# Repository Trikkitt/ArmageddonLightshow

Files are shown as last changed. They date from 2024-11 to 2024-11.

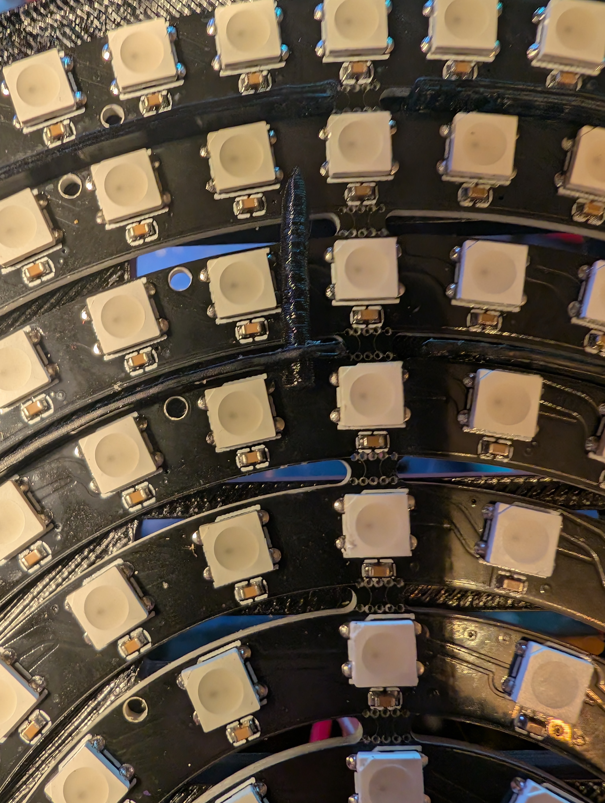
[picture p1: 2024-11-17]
Electronics/PXL_20241116_232850254.jpg

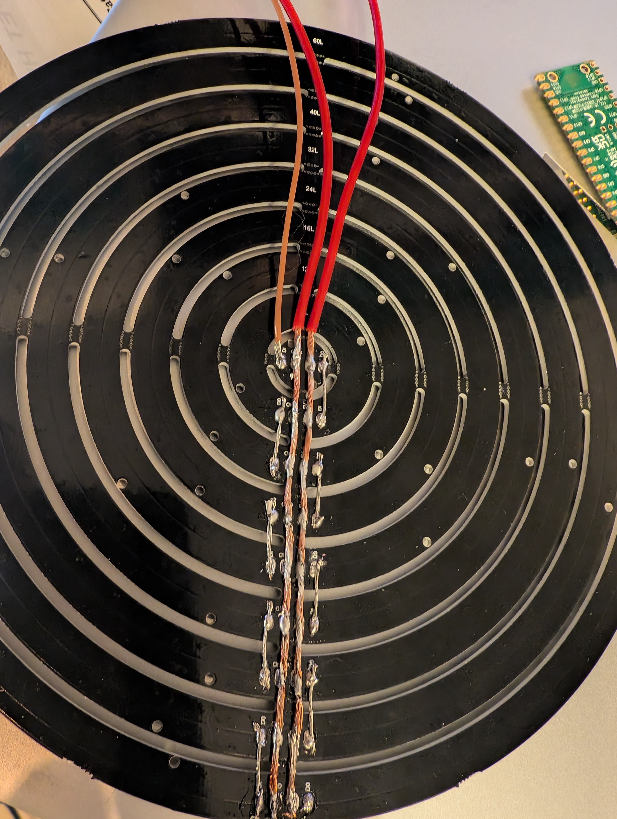
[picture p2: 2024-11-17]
Electronics/PXL_20241116_205644635.jpg

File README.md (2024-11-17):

Armageddon LaerTag Tournament.

This page will continue to be updated as the software and design is updated.  So please check back.

You can reach me via the website https://trikkitt.com or via Mastodon trikkitt@mastodon.social

Please see the readme files in each folder to explain how this all fits together.

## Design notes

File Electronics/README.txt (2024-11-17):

You will need the following:

RaspberryPi Pico or Pico W.
USB C Port - https://amzn.eu/d/fpsSOgz image is included in this folder.
Toggle Switch - Only if you want to manual power switch or a power switch to isolate the Pico from the LEDs if you're wanting to play around with the Pico software.
LED Rings - These are 241 LEDs in total over 9 rings, the smallest having 1 LED the largest having 60.  You will need to manually resolder all the connections because they're just too big and bulky - although you could expand the CPU Holder part to accommodate them it would make the back fairly chunky.
USB C 5volt 5amp Power Supply - These are readily available as power supplies for RaspberryPi 5 computers.  
Wires - Keep in mind they could be carrying up to 5amps, so make sure they're suitably specified for the task.

At maximum brightness these LEDs could be pulling up to 9amps.  For this reason the software defaults to limiting the brightness and will typically keeps its power use under 3amps using the default settings.  You can dial up the brightness, but be aware that you may find the higher power demand causes the power supply to cut out or the Pico to crash or reboot due to unstable power.  Some effects are significantly more power hungry than others so the reboots might only happen when certain effects run.  You can optionally ignore the USB C port and install something else to supply power at significantly more amps.  During tests turning all LEDs up to a value of 150 out of 255 caused power consumption to hit 5amps, while 100 out of 255 saw around 3.5amps.  The maxbrightness value in the script defaults to 0.5 which is about 128, pulling a max of about 3amps.

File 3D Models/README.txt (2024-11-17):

All models can be printed without supports except for the "CPU Mounting" model, which requires supports.  The "Pin" model should be printed with a decent brim.

For the best finish I've printed mine onto a textured bed.  The top and bottom layers of the front are printed with a Hilbert curve to avoid the appearance of long lines that can be fairly visible in some prints with monotonic top and bottom layers.  I also printed the bottom layer with one wall only to get the most detail from the phasers.  Infill is Gyroid to give the edge a nice look when illuminated.  You may want to play around with the alignment of the phasers when setting up the print.  You may wish to rotate the phasers to a position that you favour, be aware that the design makes the hanging point be exactly midway between two the retaining legs of the front.

Everything is printed in black except for the front which is printed in transparent filament along with black (or your colour of choice) for the phasers and Armageddon logo.

You need one of each item except for the clips, of which you will need 6, although I recommend printing a few spares, and the pins of which you will need 3 but you may well want to print a few spares.

I do not recommend using PLA for this, the LEDs can get quite warm.  So probably aim for a higher temperature filament.  I've used PETG just fine, which also gives everything a little flexibility.

This was created in TinkerCad and you can access the design there in https://www.tinkercad.com/things/3HTQpiZR87c-armageddon-disc-final

Assembly steps are as follows:
1 - Get your parts 3D printed and get your electronics prepared as per the electronics instructions and photos - except do not solder the LED rings to the main electronics as they must pass through a hole in one of the plastic parts.
2 - Place the LED rings onto the back plate, the raised ridges of the back plate should pop through the gaps between the rings.  Ensure the wires go through the large long opening at the back.
3 - Fully assemble the CPU holder part electronics, including attaching the LED rings wires onto the electronics in the CPU holder.
4 - Ensure the wires are as neatly retained as possible to avoid snagging.  
5 - Place the CPU retainer over the USB C port so that it holds the RaspberryPi Pico in place
6 - Place the CPU holder against the back plate so that the raised parts fit inside the grooves, then slide slowly up making sure no wires are snagged.  You will know when it has fully reached its end position as the bottom two round holes in the black plate will match up with two round holes of the CPU holder.
7 - Place the back plate onto the clear front so that the legs pop through.  Be sure to orientate the front so that your desired phaser as at the centre top.
8 - Place the clips around each clear leg to hold the front onto the back plate.

Extra things: I recommend making sure all the plastics fit together before you put the electronics into it.  This just ensures your prints are good.  The same applies to the electronics, make sure you've tested it before you fully assemble.

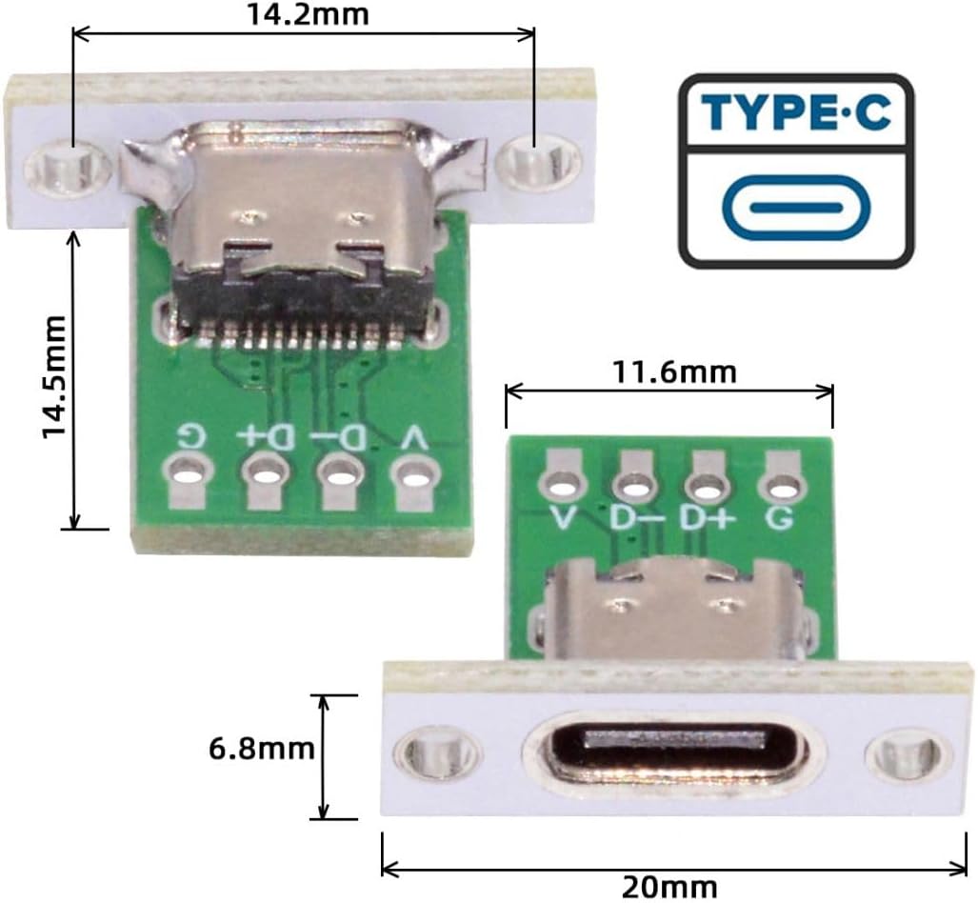
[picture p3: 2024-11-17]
Electronics/USB-C Port.jpg

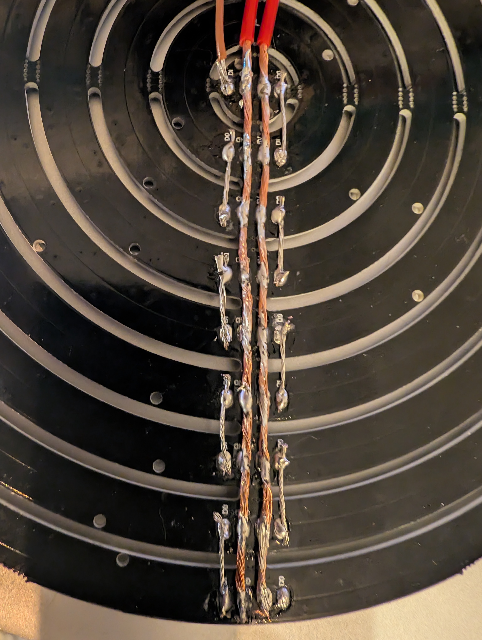
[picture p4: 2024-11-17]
Electronics/PXL_20241116_205639761.MP.jpg

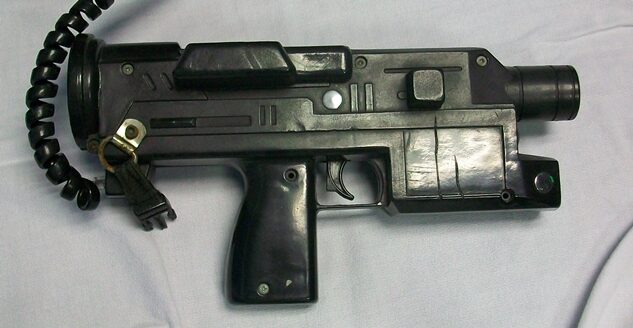
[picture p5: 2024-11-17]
SourceMedia/ActualReality Phaser.jpg

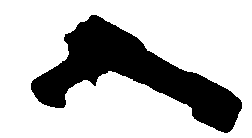
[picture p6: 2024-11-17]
SourceMedia/PhotonPhaser1.bmp

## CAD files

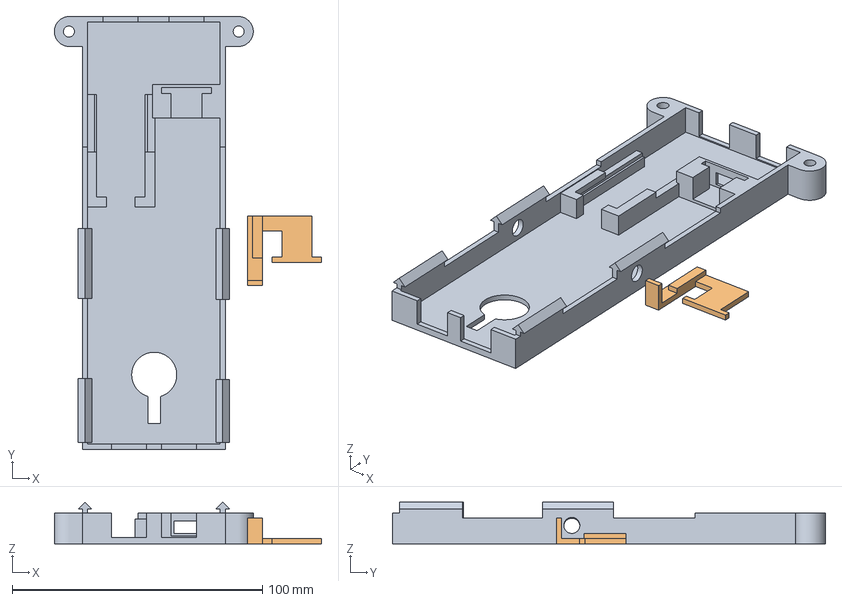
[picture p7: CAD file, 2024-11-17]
Bambu Projects/Armageddon Main CPU Holder.3mf
106.8 x 173.0 x 16.7 mm
Armageddon Disc CPU Mounting.stl
Armageddon Disc CPU Mounting Retainer.stl

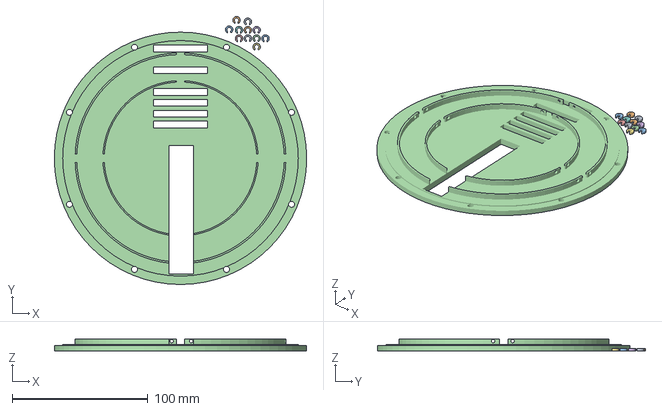
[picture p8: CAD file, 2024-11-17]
Bambu Projects/Armageddon Main Back Full.3mf
186.0 x 197.5 x 9.00 mm
Armageddon Disc Clip.stl x 11
Armageddon Disc Back.stl

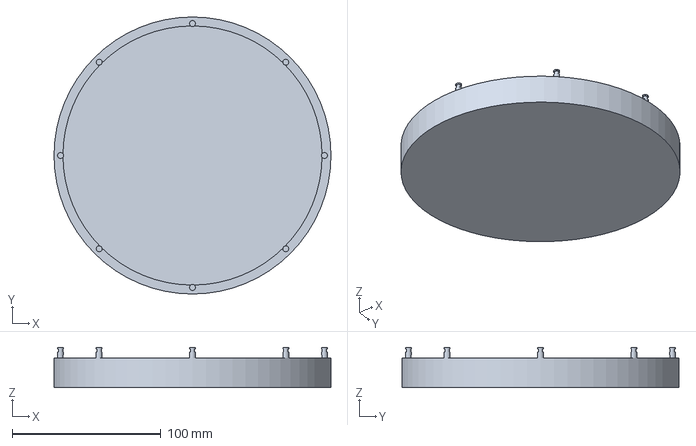
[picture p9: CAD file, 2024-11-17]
Bambu Projects/Armageddon Main Front Full.3mf
186.0 x 186.0 x 27.0 mm

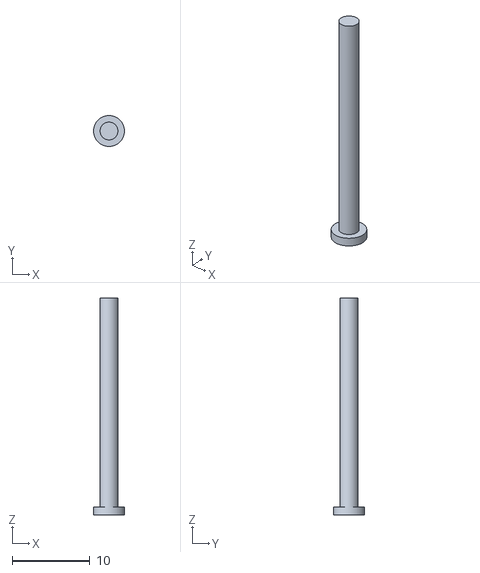
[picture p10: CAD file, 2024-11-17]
3D Models/Armageddon Disc Pin.stl
4.00 x 4.00 x 28.0

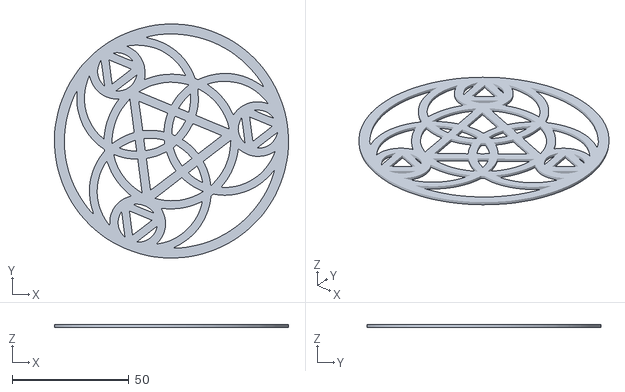
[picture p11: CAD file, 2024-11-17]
3D Models/Armageddon Disc Logo.stl
100.0 x 100.1 x 1.20

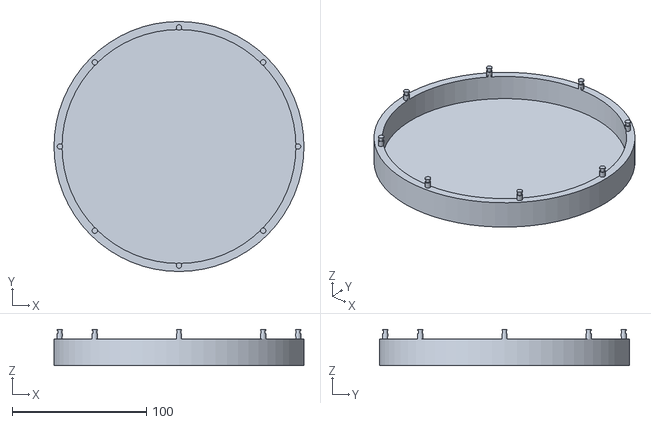
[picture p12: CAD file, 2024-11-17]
3D Models/Armageddon Disc Front.stl
186.0 x 186.0 x 27.0

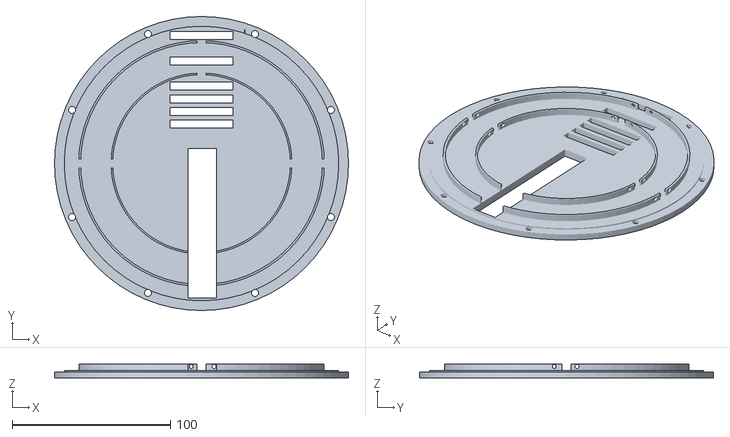
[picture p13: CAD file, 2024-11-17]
3D Models/Armageddon Disc Back.stl
186.0 x 186.0 x 9.00

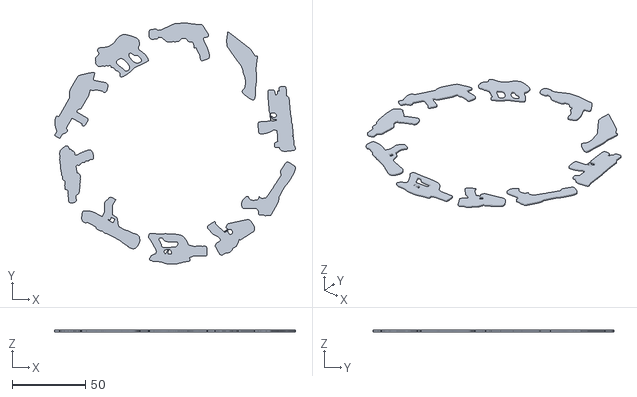
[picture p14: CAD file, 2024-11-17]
3D Models/Armageddon Disc Phasers.stl
165.0 x 165.0 x 1.20

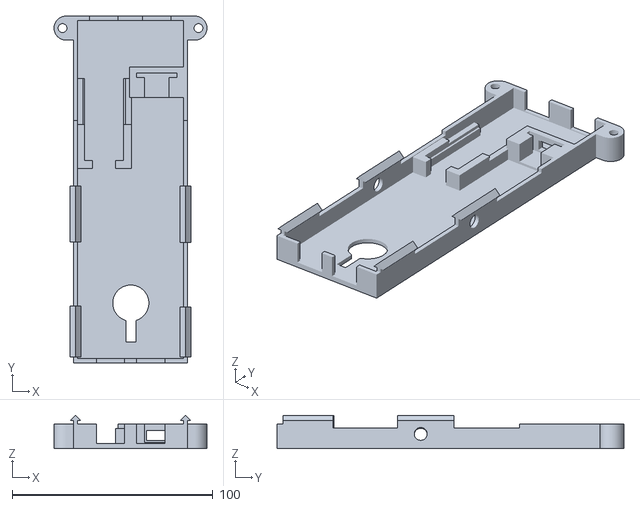
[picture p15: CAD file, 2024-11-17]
3D Models/Armageddon Disc CPU Mounting.stl
76.3 x 173.0 x 16.7

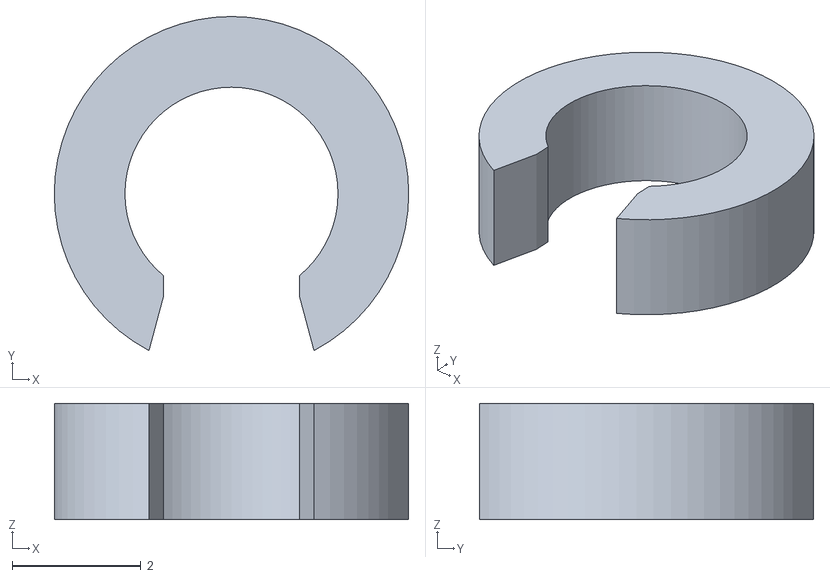
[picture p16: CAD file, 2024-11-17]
3D Models/Armageddon Disc Clip.stl
5.50 x 5.18 x 1.80

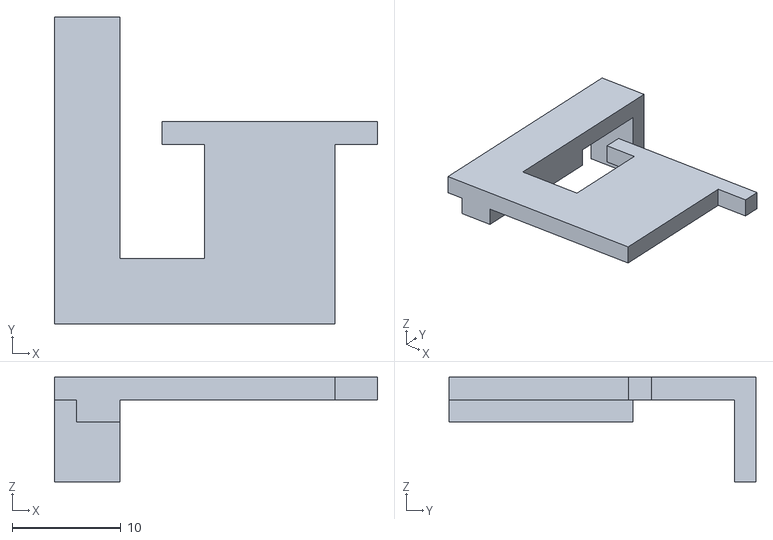
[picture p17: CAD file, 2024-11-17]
3D Models/Armageddon Disc CPU Mounting Retainer.stl
29.6 x 28.2 x 9.60

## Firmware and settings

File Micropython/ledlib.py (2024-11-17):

import machine, neopixel
import utime, random, math

def anim_sparkles(np,backgroundcolour,sparklecolour,cycles,stepdelay):
    n=np.n
    sparkles=n // 30
    sparkletracks={}

    np.fill(backgroundcolour)
    for cycle in range(cycles):
        while len(sparkletracks)<sparkles:
            pixel=random.randint(0,n-1)
            sparkletracks[pixel]=random.randint(2,4)
            np[pixel]=sparklecolour
        for pixel in sparkletracks.keys():
            sparkletracks[pixel]-=1
            if sparkletracks[pixel]==0:
                np[pixel]=backgroundcolour
                del sparkletracks[pixel]
        np.write()
        if stepdelay>0: utime.sleep_ms(stepdelay)


def anim_fadecolours(np,oldhue,newhue,steps,maxv):
    n=np.n
    if oldhue>newhue:
        bighue=oldhue
        smallhue=newhue
    else:
        bighue=newhue
        smallhue=oldhue
    huegapdirect=bighue-smallhue
    huegapwrap=(1-bighue) + oldhue
    if huegapdirect<huegapwrap:
        if oldhue>newhue:
            huestep=0-(huegapdirect/steps)
        else:
            huestep=huegapdirect/steps
    else:
        if oldhue>newhue:
            huestep=hugegapwrap/steps
        else:
            huestep=0-(hugegapwrap/steps)
    hue=oldhue
    for x in range(steps):
        colour=hsv2rgb(hue,1,maxv)
        np.fill(colour)
        np.write()
        hue+=huestep
        if hue<0: hue=1
        if hue>1: hue=0


def anim_fadecyclecolours(np,steps,maxv):
    n=np.n
    hue=0
    huestep=1/steps
    for x in range(steps):
        colour=hsv2rgb(hue,1,maxv)
        np.fill(colour)
        np.write()
        hue+=huestep


def anim_fadeupdown(np,hue,steps,direction):
    n=np.n
    s=1
    if direction==0:
        v=1
        valuestep=0-(1/steps)
    else:
        v=0
        valuestep=1/steps
    for stepcount in range(steps):
        vfixed=hsvgammacorrect(v)
        rgb=hsv2rgb(hue,s,vfixed)
        np.fill(rgb)
        np.write()
        v+=valuestep

def anim_rainbowchase(np,length,steps,stepdelay,maxv):
    n=np.n
    huestep=1/length
    hue=0
    huerange=[]
    for x in range(length):
        huerange.append(hsv2rgb(hue,1,maxv))
        hue+=huestep
        if hue>1: hue=0
    hueindex=0
    for x in range(n):
        np[x]=huerange[hueindex]
        hueindex+=1
        if hueindex>=length: hueindex=0
    np.write()
    for stepcount in range(steps):
        np.buf=np.buf[3:] + b'\x00\x00\x00'
        np[n-1]=huerange[hueindex]
        hueindex+=1
        if hueindex>=length: hueindex=0
        np.write()
        if stepdelay>0: utime.sleep_ms(stepdelay)


def anim_flashrandom(np,steps,stepdelay,maxv):
    n=np.n
    hue=0
    for step in range(steps):
        oldhue=hue
        hue=random.random()
        while closecolour(oldhue,hue):
            print("Hue bounce")
            hue=random.random()
        colour=hsv2rgb(hue,1,maxv)
        np.fill(colour)
        np.write()
        if stepdelay>0: utime.sleep_ms(stepdelay)

def anim_pixelmix(np,colour,pixelsperframe,stepdelay,maxv):
    n=np.n
    pixels=list(random_range(n))

    if colour==None:
        randomcolour=True
    else:
        randomcolour=False

    framecounter=pixelsperframe
    for step in range(n):
        pixel=pixels[step]
        if randomcolour==True:
            colour=hsv2rgb(random.random(),1,maxv)
        np[pixel]=colour
        framecounter-=1
        if framecounter==0:
            np.write()
            if stepdelay>0: utime.sleep_ms(stepdelay)
            framecounter=pixelsperframe
    if randomcolour==False:
        np.fill(colour)
        np.write()

def anim_pixelmixrandom(np,colourcount,pixelsperframe,stepdelay,holdtime,maxv):
    hue=0
    for c in range(colourcount):
        oldhue=hue
        hue=random.random()
        while closecolour(oldhue,hue):
            print("Hue bounce")
            hue=random.random()
        colour=hsv2rgb(hue,1,maxv)
        if random.randint(0,10)==5: colour=None
        anim_pixelmix(np,colour,pixelsperframe,stepdelay,maxv)
        if holdtime>0: utime.sleep_ms(holdtime)

def anim_flash(np,stepcount,blankdelay,litdelay):
    existingbuf=bytearray(len(np.buf))
    existingbuf[:]=np.buf
    for x in range(stepcount):
        np.fill((0,0,0))
        np.write()
        if blankdelay>0: utime.sleep_ms(blankdelay)
        np.buf[:]=existingbuf
        np.write()
        if litdelay>0: utime.sleep_ms(litdelay)

def anim_blank(np):
    np.fill((0,0,0))
    np.write()

def anim_onecolour(np,colour):
    np.fill(colour)
    np.write()

def anim_slowtrain(np,colour,stepdelay):
    n=np.n
    while n>0:
        np.fill((0,0,0))
        n-=1
        np[n]=colour
        np.write()
        if stepdelay>0: utime.sleep_ms(stepdelay)

def anim_rings(np,colour,stepdelay,repeatcount):
    while repeatcount>0:
        repeatcount-=1
        for count in range(0,9):
            np.fill((0,0,0))
            fillring(np,colour,count)
            np.write()
            if stepdelay>0: utime.sleep_ms(stepdelay)
        for count in range(8,-1,-1):
            np.fill((0,0,0))
            fillring(np,colour,count)
            np.write()
            if stepdelay>0: utime.sleep_ms(stepdelay)
        
def anim_rainbowring(np,stepdelay,huestep,repeatcount,maxv):
    while repeatcount>0:
        hue=1
        repeatcount-=1
        while hue>0:
            temphue=hue
            hue-=huestep
            for ringnumber in range(0,9):
                fillring(np,hsv2rgb(temphue,1,maxv),ringnumber)
                temphue-=huestep
                if temphue<0:
                    temphue+=1
            np.write()
            if stepdelay>0: utime.sleep_ms(stepdelay)

ringstart=[0,1,9,21,37,61,93,133,181]
ringlength=[1,8,12,16,24,32,40,48,60]

def fillring(np,colour,ringnumber):
    n=ringstart[ringnumber]
    c=ringlength[ringnumber]
    while c>0:
        np[n]=colour
        c-=1
        n+=1
        
    

def closecolour(oldhue,newhue):
    closevalue=0.15
    if oldhue>newhue:
        bighue=oldhue
        smallhue=newhue
    else:
        bighue=newhue
        smallhue=oldhue
    huegap=bighue-smallhue
    if huegap<closevalue: return(True)
    huegap=(1-bighue) + smallhue
    if huegap<closevalue: return(True)
    return(False)

def random_range(maximum):
    found=0
    mapping=lambda i: i+1
    value=random.randint(0,maximum)
    offset = random.randint(0,maximum) * 2 + 1
    multiplier = 4*(maximum//4) + 1
    modulus = int(2**math.ceil(math.log2(maximum)))
    while found<maximum:
        if value<maximum:
            found+=1
            yield mapping(value-1)
        value=(value*multiplier + offset) % modulus

def hsv2rgb(h, s, v):
        if s == 0.0: return (v, v, v)
        i = int(h*6.) # XXX assume int() truncates!
        f = (h*6.)-i; p,q,t = v*(1.-s), v*(1.-s*f), v*(1.-s*(1.-f)); i%=6
        v=round(v * 255)
        p=round(p * 255)
        t=round(t * 255)
        q=round(q * 255)
        if i == 0: return (v, t, p)
        if i == 1: return (q, v, p)
        if i == 2: return (p, v, t)
        if i == 3: return (p, q, v)
        if i == 4: return (t, p, v)
        if i == 5: return (v, p, q)

def hsvgammacorrect(v):
    index=int(v*255)
    return(gammatable[index]/255)

gammatable=[
    0,  0,  0,  0,  0,  0,  0,  0,  0,  0,  0,  0,  0,  0,  0,  0,
    0,  0,  0,  0,  0,  0,  0,  0,  0,  0,  0,  0,  1,  1,  1,  1,
    1,  1,  1,  1,  1,  1,  1,  1,  1,  2,  2,  2,  2,  2,  2,  2,
    2,  3,  3,  3,  3,  3,  3,  3,  4,  4,  4,  4,  4,  5,  5,  5,
    5,  6,  6,  6,  6,  7,  7,  7,  7,  8,  8,  8,  9,  9,  9, 10,
   10, 10, 11, 11, 11, 12, 12, 13, 13, 13, 14, 14, 15, 15, 16, 16,
   17, 17, 18, 18, 19, 19, 20, 20, 21, 21, 22, 22, 23, 24, 24, 25,
   25, 26, 27, 27, 28, 29, 29, 30, 31, 32, 32, 33, 34, 35, 35, 36,
   37, 38, 39, 39, 40, 41, 42, 43, 44, 45, 46, 47, 48, 49, 50, 50,
   51, 52, 54, 55, 56, 57, 58, 59, 60, 61, 62, 63, 64, 66, 67, 68,
   69, 70, 72, 73, 74, 75, 77, 78, 79, 81, 82, 83, 85, 86, 87, 89,
   90, 92, 93, 95, 96, 98, 99,101,102,104,105,107,109,110,112,114,
  115,117,119,120,122,124,126,127,129,131,133,135,137,138,140,142,
  144,146,148,150,152,154,156,158,160,162,164,167,169,171,173,175,
  177,180,182,184,186,189,191,193,196,198,200,203,205,208,210,213,
  215,218,220,223,225,228,231,233,236,239,241,244,247,249,252,255 ]

np = neopixel.NeoPixel(machine.Pin(0),242)
maxbrightness=0.5

while True:
    effectid=random.randint(1,19)
    #effectid=19
#for effectid in range(15,16):
    
    if effectid==1:
        anim_rainbowchase(np,5,400,30,maxbrightness)
    if effectid==2:
        anim_pixelmixrandom(np,10,3,0,2000,maxbrightness)
    if effectid==3:
        hue=random.random()
        colour=hsv2rgb(hue,1,maxbrightness)
        anim_pixelmix(np,colour,5,0,maxbrightness)
        anim_sparkles(np,colour,(255,255,255),350,1)
    if effectid==4:
        anim_pixelmix(np,(0,0,255),5,0,maxbrightness)
        anim_sparkles(np,(0,0,255),(255,255,255),450,1)
    if effectid==5:
        anim_flashrandom(np,30,250,maxbrightness)
        anim_pixelmix(np,(0,0,0),5,0,maxbrightness)
    if effectid==6:
        anim_rainbowchase(np,50,400,2,maxbrightness)
    if effectid==7:
        anim_pixelmix(np,(255,0,100),5,0,maxbrightness)
        anim_sparkles(np,(255,0,100),(255,255,255),450,1)
    if effectid==8:
        anim_pixelmix(np,None,5,0,maxbrightness)
    if effectid==9:
        anim_rainbowchase(np,300,500,0,maxbrightness)
    if effectid==10:
        anim_fadecyclecolours(np,200,maxbrightness)
        anim_fadecyclecolours(np,200,maxbrightness)
        anim_fadecyclecolours(np,200,maxbrightness)
    if effectid==11:
        rainbowlen=random.randint(6,250)
        avglen=(250-rainbowlen)//8
        delaylen=random.randint(avglen-3,avglen+3)
        if delaylen<0: delaylen=0
        cycles=200+(150*((31-delaylen)/6))
        anim_rainbowchase(np,rainbowlen,cycles,delaylen,maxbrightness)
    if effectid==12:
        colourcount=random.randint(10,50)
        colourdelay=random.randint(200,400)
        anim_flashrandom(np,colourcount,colourdelay,maxbrightness)
    if effectid==13:
        colourdelay=random.randint(25,400)
        repeatcount=random.randint(2,5)
        for x in range(repeatcount):
            anim_fadecyclecolours(np,colourdelay,maxbrightness)
    if effectid==14:
        anim_pixelmix(np,None,5,0,maxbrightness)
        anim_pixelmix(np,(0,0,0),10,0,maxbrightness)
        anim_pixelmix(np,None,5,0,maxbrightness)
        anim_pixelmix(np,(0,0,0),10,0,maxbrightness)
        anim_pixelmix(np,None,5,0,maxbrightness)
        anim_pixelmix(np,(0,0,0),10,0,maxbrightness)
    if effectid==15:
        anim_pixelmix(np,None,5,0,maxbrightness)
        anim_flash(np,20,150,50)
    if effectid==16:
        rndhue=random.random()
        colour=hsv2rgb(rndhue,1,1)
        anim_slowtrain(np,colour,0)
    if effectid==17:
        rndhue=random.random()
        colour=hsv2rgb(rndhue,1,maxbrightness)
        anim_rings(np,colour,100,1)
    if effectid==18:
        #anim_rainbowring(np,40,0.04,1,maxbrightness)
        #anim_rainbowring(np,20,0.05,1,maxbrightness)
        #anim_rainbowring(np,10,0.08,10,maxbrightness)
        anim_rainbowring(np,0,0.01,1,maxbrightness)
    if effectid==19:
        #anim_rainbowring(np,40,0.04,1,maxbrightness)
        #anim_rainbowring(np,20,0.05,1,maxbrightness)
        anim_rainbowring(np,10,0.08,10,maxbrightness)
        #anim_rainbowring(np,0,0.01,1,maxbrightness)
        
